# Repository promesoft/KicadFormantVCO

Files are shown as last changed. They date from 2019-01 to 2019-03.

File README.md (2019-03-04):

# KicadFormantVCO
Started as a Clone of http://sebholzapfel.com/modular-synth-vco-design-build/

# Rev C1 - New PCB

## Status - Rev C1 Produced - received - tested
### Errata
 - RV7 reversed (FM)

### Issues and Notes
 - Consider 10 pin Doepfer (will make routing easier)
 - Place SMD on backside to make better room for components and traces
 - Consider TL074/MC33079
 - 1N4148 footprint - reconsider
 - trimmers on back
 - add resistor to coarse freq trim
 - add swich on PCB for LFO
 - Replace jack connectors 
 - Silk screen is off..
### Alternative components
 - Next should not rely on the LM3046 BJT as its not easy to come by.
 - Next should not rely on the REF102/AD587 as its more expensive than most and not certain if its needed.
 - Consider NAND alternative in oscilator core (74LS00 used for test without problems)
 - consider 1nF cap for VCO core (now 470p)
 - Q4 and Q5 was 2N2222 for test
 - Q1,2,3 was S9013 for the test
 - Op amp was LM833 for the test
 - Mix of 1uF and 4u7 decoupling caps for the test
 - R12 = 390k for the test
 - RV8 = 500R for the test
 - RV7=RV9 = 50k for the test
 - R9 = 240R for the test
 - R18 = 18k for the test
 - R24 = 5k6 for the test
 - R28 = 330R for the test
 
## Physical Construction

## Features

# Rev B
## Old README.md For original PCB
# SMD Formant VCO Prototype
KiCAD files for eurorack-compatible formant-based VCO design. Mostly created just to learn KiCAD.

Video on construction/operation is here: https://www.youtube.com/watch?v=rq4ovZ2om6k

## ERRATA [V1A] (To be fixed in future revision)
- The TL071 op-amp in the CAD files is arbitrary, I actually used an LM358. Just use whatever 8-pin SOIC dual op-amp you like.
- Diodes (D1..) are incorrect footprint. Change this to suit.
- 10V reference chip, VCC is not connected to +V properly. This must be bridged.
- +/-15V designator actually should be +/-12V to match eurorack. Doesn't make any electrical difference, but it's what the schematic says.
- Be careful with tantalum capacitor orientation, check with schematic. Silkscreen 'line' is negative, not positive.

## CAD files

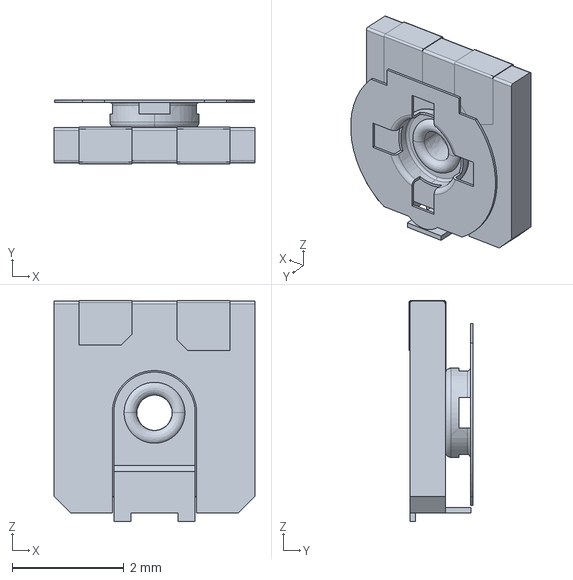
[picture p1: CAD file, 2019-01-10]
models/TC-33X-2.stp
3.60 x 1.15 x 3.96 mm

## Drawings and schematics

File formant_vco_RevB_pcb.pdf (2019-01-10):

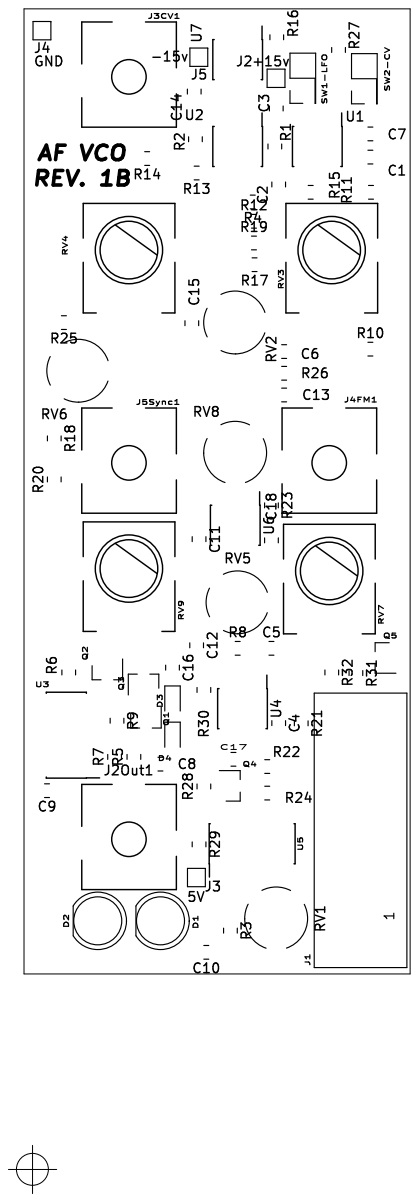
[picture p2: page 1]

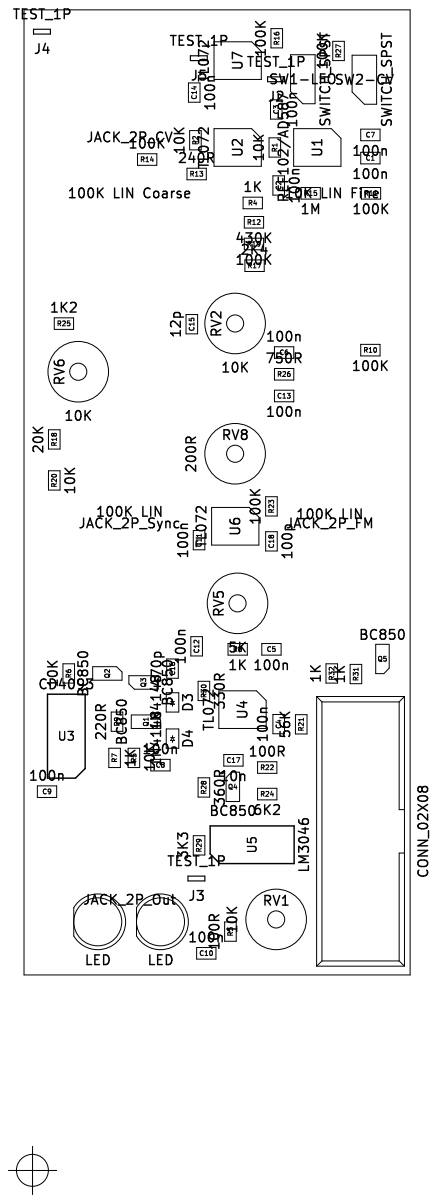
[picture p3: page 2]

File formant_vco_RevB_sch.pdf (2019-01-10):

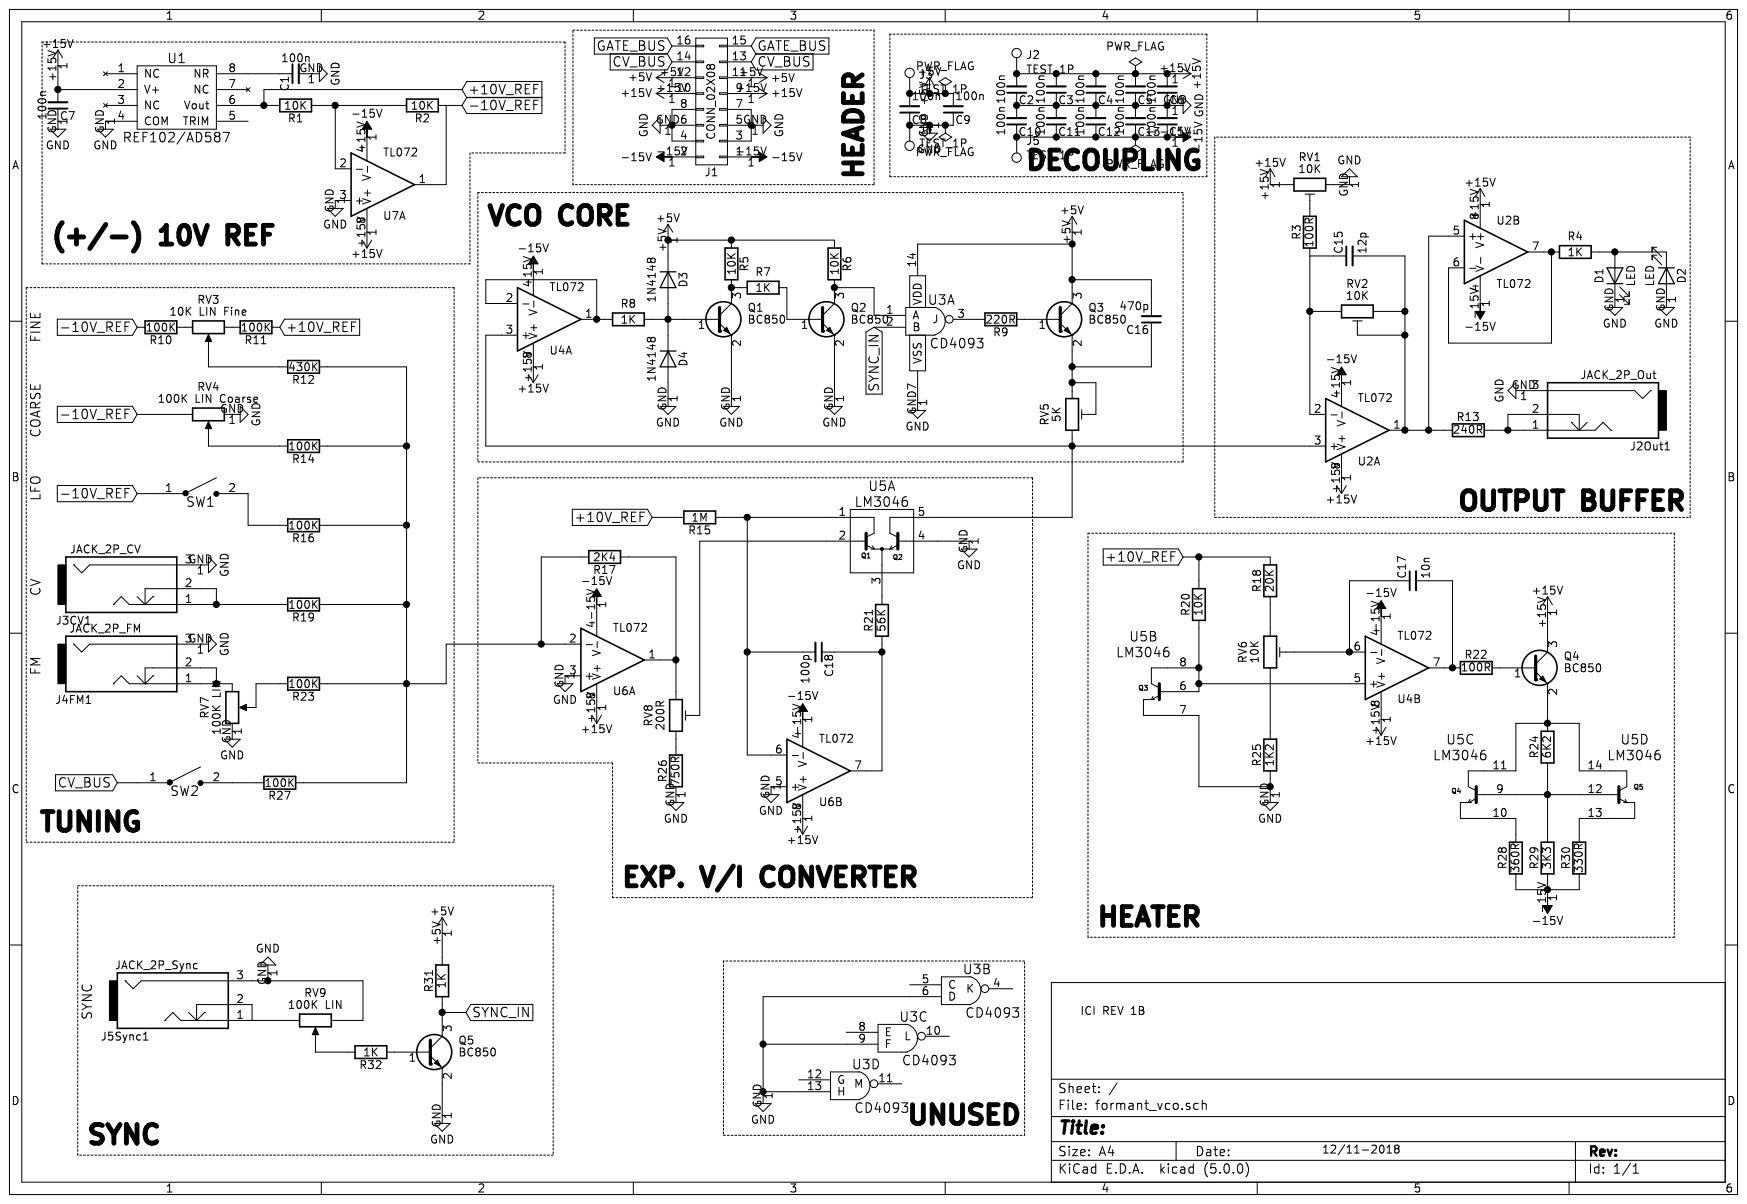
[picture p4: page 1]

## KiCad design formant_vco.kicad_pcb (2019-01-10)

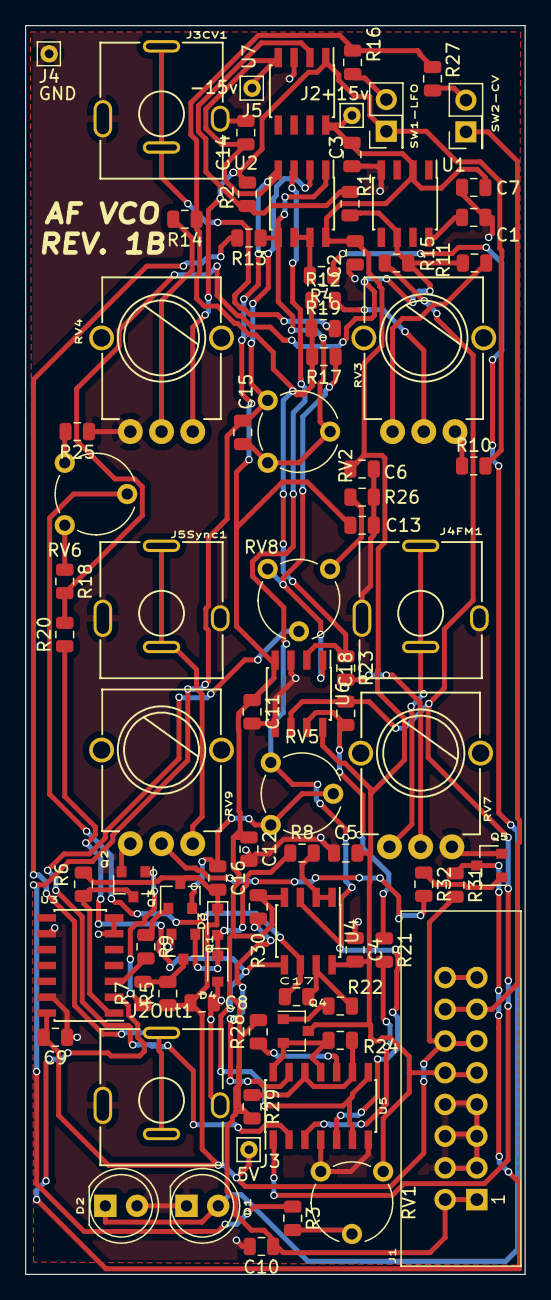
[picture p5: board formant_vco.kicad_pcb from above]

Board: 2 copper layers, 40.0 x 100.0 mm, 86 parts (0 on the bottom side), 55 nets.

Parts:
C1, C2, C3, C4, C5, C6, C7, C8, C9, C10, C11, C12, C13, C14: 100n; C_0805_2012Metric
C15: 12p; C_0805_2012Metric
C16: 470p; C_0805_2012Metric
C17: 10n; C_0805_2012Metric
C18: 100p; C_0805_2012Metric
D1, D2: LED; LED_D5.0mm
D3, D4: 1N4148; D_0805
J1: CONN_02X08; IDC_Header_Straight_16pins
J2, J3, J4, J5: TEST_1P; Pin_D0.7mm_L6.5mm_W1.8mm_FlatFork
J2Out1: JACK_2P_Out; pj301bm
J3CV1: JACK_2P_CV; pj301bm
J4FM1: JACK_2P_FM; pj301bm
J5Sync1: JACK_2P_Sync; pj301bm
Q1, Q2, Q3, Q4, Q5: BC850; SOT-23
R1, R2, R5, R6, R20: 10K; R_0805_2012Metric
R3, R22: 100R; R_0805_2012Metric
R4, R7, R8, R31, R32: 1K; R_0805_2012Metric
R9: 220R; R_0805_2012Metric
R10, R11, R14, R16, R19, R23, R27: 100K; R_0805_2012Metric
R12: 430K; R_0805_2012Metric
R13: 240R; R_0805_2012Metric
R15: 1M; R_0805_2012Metric
R17: 2K4; R_0805_2012Metric
R18: 20K; R_0805_2012Metric
R21: 56K; R_0805_2012Metric
R24: 6K2; R_0805_2012Metric
R25: 1K2; R_0805_2012Metric
R26: 750R; R_0805_2012Metric
R28: 360R; R_0805_2012Metric
R29: 3K3; R_0805_2012Metric
R30: 330R; R_0805_2012Metric
RV1, RV2, RV6: 10K; Potentiometer_Piher_PT-6-V_Vertical
RV3: 10K LIN Fine; alpha_d_pot_vert
RV4: 100K LIN Coarse; alpha_d_pot_vert
RV5: 5K; Potentiometer_Piher_PT-6-V_Vertical
RV7, RV9: 100K LIN; alpha_d_pot_vert
RV8: 200R; Potentiometer_Piher_PT-6-V_Vertical
SW1-LFO, SW2-CV: SWITCH_SPST; Pin_Header_Straight_2x01_Pitch2.54mm
U1: REF102/AD587; SOIC-8_3.9x4.9mm_P1.27mm
U2, U4, U6, U7: TL072; SOIC-8_3.9x4.9mm_P1.27mm
U3: CD4093; SOIC-14_3.9x8.7mm_Pitch1.27mm
U5: LM3046; SOIC-14_3.9x8.7mm_Pitch1.27mm

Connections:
+5V: C8.2, C9.2, C16.2, D3.1, J1.11, J1.12, J3.1, Q3.3, R5.1, R6.1, R31.2, U3.14
+10V_REF: R1.2, R11.1, R15.2, R18.2, R20.2, U1.6
+15V: C2.2, C3.2, C4.2, C5.2, C6.2, C7.2, J1.9, J1.10, J2.1, Q4.3, RV1.3, U1.2, U2.8, U4.8, U6.8, U7.8
-10V_REF: R2.1, R10.2, RV4.3, SW1-LFO.1, U7.1
-15V: C10.1, C11.1, C12.1, C13.1, C14.1, J1.1, J1.2, J5.1, R28.2, R29.2, R30.2, U2.4, U4.4, U6.4, U7.4
CV_BUS: J1.13, J1.14, SW2-CV.1
GATE_BUS: J1.15, J1.16
GND: C1.2, C2.1, C3.1, C4.1, C5.1, C6.1, C7.1, C8.1, C9.1, C10.2, C11.2, C12.2, C13.2, C14.2, D1.1, D2.2, D4.2, J1.3, J1.4, J1.5, J1.6, J1.7, J1.8, J2Out1.3, J3CV1.3, J4.1, J4FM1.3, J5Sync1.3, Q1.2, Q2.2, Q5.2, R25.1, R26.1, RV1.1, RV4.1, RV7.3, RV9.1, U1.4, U3.6, U3.7, U3.9, U3.13, U5.4, U5.7, U6.3, U6.5, U7.3
unnamed: C1.1, U1.8
unnamed: C15.1, R3.1, RV2.3, U2.2
unnamed: C15.2, R13.1, RV2.1, RV2.2, U2.1, U2.5
unnamed: C16.1, Q3.2, RV5.1, RV5.2
unnamed: C17.1, RV6.2, U4.6
unnamed: C17.2, R22.1, U4.7
unnamed: C18.1, R21.1, U6.7
unnamed: C18.2, R15.1, U5.1, U6.6
unnamed: D1.2, D2.1, R4.1
unnamed: D3.2, D4.1, Q1.1, R8.1
unnamed: J2Out1.1, J2Out1.2, R13.2
unnamed: J3CV1.1, J3CV1.2, R19.2
unnamed: J4FM1.1, J4FM1.2, RV7.1
unnamed: J5Sync1.1, J5Sync1.2, RV9.3
unnamed: Q1.3, R5.2, R7.2
unnamed: Q2.1, R7.1
unnamed: Q2.3, R6.2, U3.1
unnamed: Q3.1, R9.1
unnamed: Q4.1, R22.2
unnamed: Q4.2, R24.1, U5.11, U5.14
unnamed: Q5.1, R32.1
unnamed: R1.1, R2.2, U7.2
unnamed: R3.2, RV1.2
unnamed: R4.2, U2.6, U2.7
unnamed: R8.2, U4.1, U4.2
unnamed: R9.2, U3.3
unnamed: R10.1, RV3.3
unnamed: R11.2, RV3.1
unnamed: R12.1, R14.1, R16.1, R17.2, R19.1, R23.1, R27.1, U6.2
unnamed: R12.2, RV3.2
unnamed: R14.2, RV4.2
unnamed: R16.2, SW1-LFO.2
unnamed: R17.1, RV8.1, U6.1
unnamed: R18.1, RV6.1
unnamed: R20.1, U4.5, U5.6, U5.8
unnamed: R21.2, U5.3
unnamed: R23.2, RV7.2
unnamed: R24.2, R29.1, U5.9, U5.12
unnamed: R25.2, RV6.3
unnamed: R26.2, RV8.3
unnamed: R27.2, SW2-CV.2
unnamed: R28.1, U5.10
unnamed: R30.1, U5.13
unnamed: R32.2, RV9.2
unnamed: RV5.3, U2.3, U4.3, U5.5
unnamed: RV8.2, U5.2
SYNC_IN: Q5.3, R31.1, U3.2

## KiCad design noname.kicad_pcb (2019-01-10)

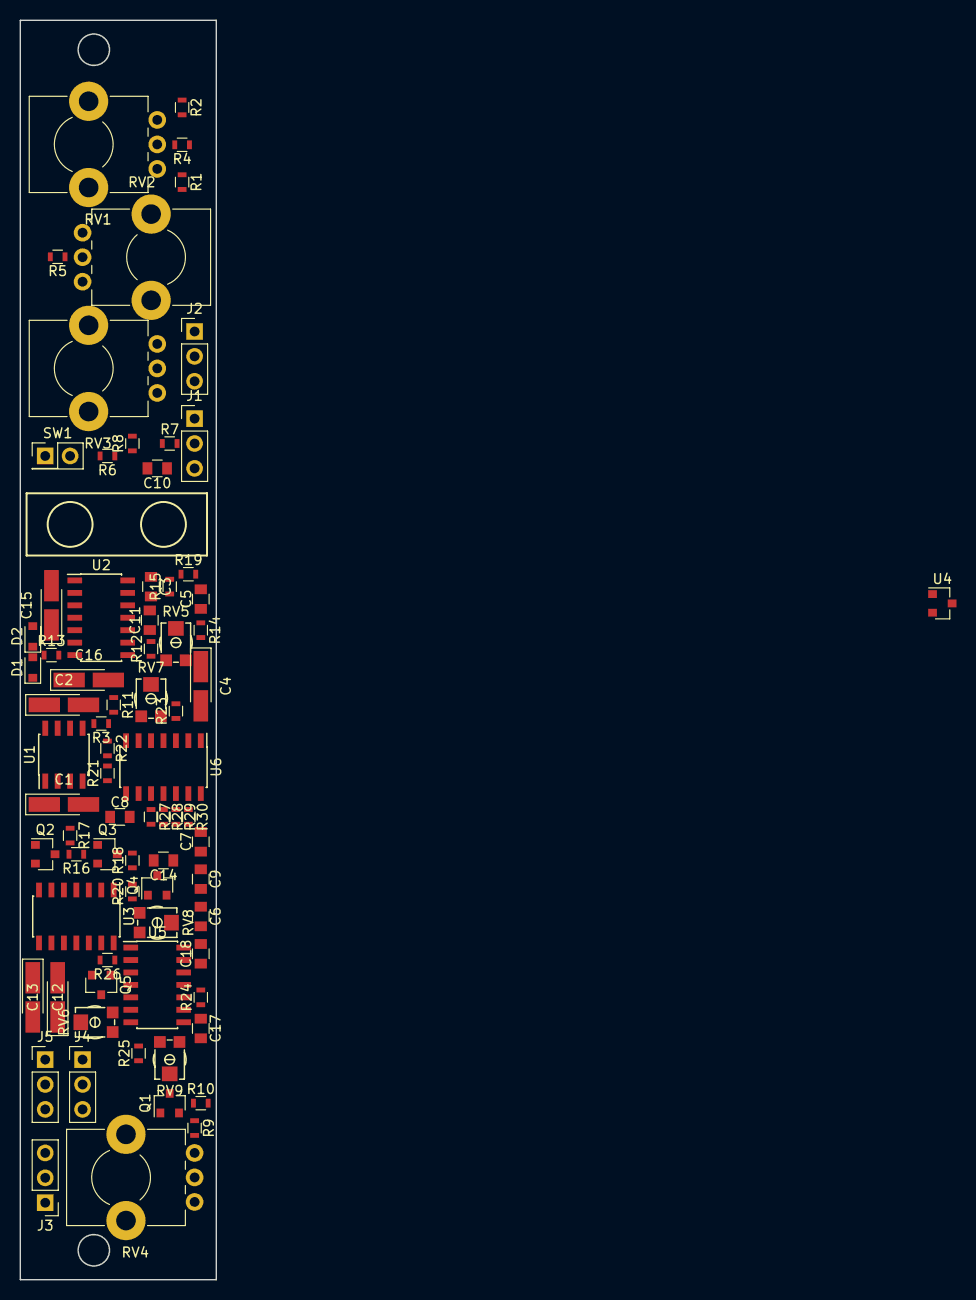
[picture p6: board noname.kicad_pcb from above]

Board: 2 copper layers, 20.0 x 128.5 mm, 76 parts (0 on the bottom side), 51 nets, no tracks yet.

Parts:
C1, C2: 1u; CP_Tantalum_Case-A_EIA-3216-18_Hand
C3: 100p; C_0805
C4: 100u; CP_Tantalum_Case-A_EIA-3216-18_Hand
C5, C6, C7, C8, C9, C10, C11: 100n; C_0805
C12, C13, C15, C16: 10u; CP_Tantalum_Case-A_EIA-3216-18_Hand
C14: 470p; C_0805
C17: 12p; C_0805
C18: 10n; C_0805
D1, D2: 1N4148; D_0805
J1, J2, J3: JACK_2P; Pin_Header_Straight_1x03_Pitch2.54mm
J4: CONN_01X03; Pin_Header_Straight_1x03_Pitch2.54mm
J5: JACK_2P; Socket_Strip_Straight_1x03_Pitch2.54mm
Q1, Q2, Q3, Q4, Q5: BC850; SOT-23
R1, R2, R5, R6, R7, R8: 100K; R_0603
R3, R11, R16, R18, R21: 10K; R_0603
R4: 430K; R_0603
R9, R10, R13, R17: 1K; R_0603
R12: 2K4; R_0603
R14: 750R; R_0603
R15: 1M; R_0603
R19: 56K; R_0603
R20: 220R; R_0603
R22: 20K; R_0603
R23: 1K2; R_0603
R24, R26: 100R; R_0603
R25: 240R; R_0603
R27: 360R; R_0603
R28: 6K2; R_0603
R29: 3K3; R_0603
R30: 330R; R_0603
RV1: 10K LIN; Potentiometer_Bourns_PTV09A-1_Horizontal
RV2, RV3, RV4: 100K LIN; Potentiometer_Bourns_PTV09A-1_Horizontal
RV5: 200R; bourns_trimmer_tc33x-2
RV6: 5K; bourns_trimmer_tc33x-2
RV7, RV8, RV9: 10K; bourns_trimmer_tc33x-2
SW1: SWITCH_SPST; Pin_Header_Straight_2x01_Pitch2.54mm
U1: REF102; SOIC-8_3.9x4.9mm_Pitch1.27mm
U2, U5: TL074; SOIC-14_3.9x8.7mm_Pitch1.27mm
U3: CD4093; SOIC-14_3.9x8.7mm_Pitch1.27mm
U4: 7805; SOT-23
U6: LM3046; SOIC-14_3.9x8.7mm_Pitch1.27mm

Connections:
+5V: C4.1, C5.2, C14.2, D1.1, Q4.3, R10.2, R16.1, R18.1, U3.14
+10V_REF: R2.1, R3.2, R15.2, R21.2, R22.2, U1.6
+15V: C6.2, C8.2, C10.2, C12.1, C15.1, J4.1, Q5.3, RV8.3, U2.4, U5.4
-10V_REF: R1.2, R11.1, RV2.3, SW1.1, U2.1
-15V: C7.1, C9.1, C11.1, C13.2, C16.2, J4.3, R27.2, R29.2, R30.2, U2.11, U5.11
GND: C1.2, C2.2, C4.2, C5.1, C6.1, C7.2, C8.1, C9.2, C10.1, C11.2, C12.2, C13.1, C15.2, C16.1, D2.2, J1.3, J2.3, J3.3, J4.2, J5.3, Q1.2, Q2.2, Q3.2, R14.1, R23.1, RV2.1, RV3.3, RV4.1, RV8.1, U1.4, U2.3, U2.10, U2.12, U3.7, U6.4, U6.7
unnamed: C1.1, U1.2
unnamed: C2.1, U1.8
unnamed: C3.1, R19.1, U2.14
unnamed: C3.2, R15.1, U2.13, U6.1
unnamed: C14.1, Q4.2, RV6.1, RV6.2
unnamed: C17.1, R24.1, RV9.3, U5.9
unnamed: C17.2, R25.1, RV9.1, RV9.2, U5.8
unnamed: C18.1, RV7.2, U5.13
unnamed: C18.2, R26.1, U5.14
unnamed: D1.2, D2.1, Q2.1, R13.1
unnamed: J1.1, J1.2, R7.2
unnamed: J2.1, J2.2, RV3.1
unnamed: J3.1, J3.2, RV4.3
unnamed: J5.1, J5.2, R25.2
unnamed: Q1.1, R9.1
unnamed: Q2.3, R16.2, R17.2
unnamed: Q3.1, R17.1
unnamed: Q3.3, R18.2, U3.1
unnamed: Q4.1, R20.1
unnamed: Q5.1, R26.2
unnamed: Q5.2, R28.1, U6.11, U6.14
unnamed: R1.1, RV1.3
unnamed: R2.2, RV1.1
unnamed: R4.2, RV1.2
unnamed: R5.2, RV2.2
unnamed: R6.2, SW1.2
unnamed: R8.2, RV3.2
unnamed: R9.2, RV4.2
unnamed: R3.1, R11.2, U2.2
unnamed: R12.1, RV5.1, U2.8
unnamed: R4.1, R5.1, R6.1, R7.1, R8.1, R12.2, U2.9
unnamed: R13.2, U2.6, U2.7
unnamed: R14.2, RV5.3
unnamed: R19.2, U6.3
unnamed: R20.2, U3.3
unnamed: R21.1, U5.12, U6.6, U6.8
unnamed: R22.1, RV7.1
unnamed: R23.2, RV7.3
unnamed: R24.2, RV8.2
unnamed: R27.1, U6.10
unnamed: R28.2, R29.1, U6.9, U6.12
unnamed: R30.1, U6.13
unnamed: RV5.2, U6.2
unnamed: RV6.3, U2.5, U5.10, U6.5
SYNC_IN: Q1.3, R10.1, U3.2
